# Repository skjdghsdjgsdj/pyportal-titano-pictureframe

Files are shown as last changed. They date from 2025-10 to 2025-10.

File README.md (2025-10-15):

# PyPortal Titano Picture Frame

Use a [PyPortal Titano](https://www.adafruit.com/product/4444) as a little picture frame with images pulled from your favorites in [Immich](https://immich.app/).

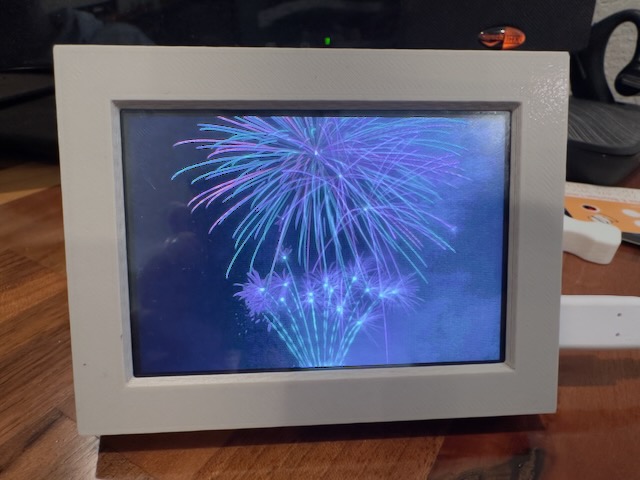
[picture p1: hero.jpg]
The PyPortal Titano picture frame in action


The project is structured into three main parts:

* `client`: the CircuitPython code that runs on the PyPortal Titano
* `server`: A Python Flask HTTP server that connects to your Immich instance and does image conversions and other middleware between Immich and the picture frame
* `hardware`: The OpenSCAD files for the 3D printed parts

## Setup

### Things you'll need

For hardware, you'll need this stuff. Yay, no soldering or wiring at all!

* An [Adafruit PyPortal Titano](https://www.adafruit.com/product/4444)
* A microSD card
* A 3D printer
* A USB C-to-C cable
* A USB C power supply
* 8× M3x4 screws
* A computer with a USB C port and a microSD card reader, or an SD card reader with a microSD-to-SD adapter (many cards come with this)

You might want a USB C cable with a right angle connector, but it's not necessary.

You also need:

* [Immich](https://immich.app/) up and running somewhere
* A computer that runs 24/7 to run a Python server
* A very basic understanding of how to run Python scripts and install packages

Each picture takes up about 500 KB of space on the card. A 1 GB card therefore can hold about 2000 pictures, and a 16 GB card holds around 30,000. microSD cards are pretty cheap so I'd suggest getting a reasonably big one, or a good sized one you already have laying around. The card isn't written to very often, so I wouldn't bother with "endurance" cards or other expensive ones. Besides, if the SD card dies, just put in a new one and the picture frame will sync everything automatically again.

### Building everything

First, set up the software environment for your server. The server acts as a bridge between the picture frame and Immich to download images and convert them to a format compatible with the PyPortal Titano. The PyPortal Titano doesn't talk directly to Immich.

1. Clone this Git repository, or download a `.zip` of it and extract it.
2. `cd` to the `server` directory. All the subsequent commands you'll run should be within the `server` directory.
3. Copy `.env.example` to `.env`, then modify `.env` as documented within that file.
4. Create a virtual environment: `cd` to the `server` directory, create an environment with `python3 -m venv ./.venv`, and activate it with `source .venv/bin/activate`.
5. Install the necessary Python libraries with `pip3 install -r requirements.txt`
6. Launch the server with `python3 server.py`. Note the IP address and port number of your server; you'll need that next.

Before moving on, open your Immich instance and favorite some pictures (not videos). The server will pick from your favorites when listing the available pictures for the picture frame.

With the server done, you can move into the rest of the assembly.

1. [Install CircuitPython 10 on the board](https://learn.adafruit.com/adafruit-pyportal-titano/circuitpython#set-up-circuitpython-quick-start-3050161).
2. Print the enclosure:
    * Use 0.2mm layer height.
    * Use any filament you want. PLA is easiest.
    * Do not use supports.
    * Orient the parts such that the case is upside down, the backplate prints with the flat part facing down, and the stand as-is.
3. Format the microSD card in your computer as FAT32 for cards up to and including 32 GB, or exFAT for cards larger than 32 GB (instructions for [macOS](https://support-en.sandisk.com/app/answers/detailweb/a_id/35101/~/steps-to-format-a-memory-card-on-macos), [Windows](https://support-en.sandisk.com/app/answers/detailweb/a_id/9063/~/instructions-to-format-a-memory-card-on-windows)). This will delete all the data on the card!
3. Assemble the enclosure:
    1. If installed, peel off the protective plastic cover on the PyPortal Titano's screen.
    2. Insert the microSD card into the board until it clicks into place.
    3. Place the board into the enclosure with the screen facing the opening and the USB C port and microSD card slot facing their respective locations.
    4. Use 4× screws to secure the board into the enclosure's standoffs. Do not tighten the screws any further than necessary to keep the board in place.
    5. Screw the backplate into place with the other 4× screws. Orient the backplate so the hole labeled "reset" aligns with the reset button on the board. Again, only tighten the screws as much as necessary.
    6. Install the stand by pressing one side of it into the mounting point on the backplate, then gently squeezing the stand into place and pressing the other side into its mounting point.
    7. If you want to use the ambient light sensor, shove a little piece of 1.75mm transparent filament (any material) into the hole near the microSD card until it's flush with the outside of the case. If you don't care about having the screen adjust its brightness automatically, or you odn't have any transparent filament, you can skip this.
4. Install the software for the picture frame:
    1. Clone this Git repository, or download it as a `.zip` and extract it.
    2. Copy `client/settings.toml.example` to `client/settings.toml` and open it in a text editor.
    3. At a minimum, look at the section "Settings you'll have to change" and change those values. There are more settings you can change if you want, but it's not necessary.
    4. Copy everything in the `client` directory, but not the `client` directory itself, to the `CIRCUITPY` drive. It might take a while. Eventually the board should reboot, connect to Wi-Fi, and start showing your pictures!

## Usage

It's very easy: favorite a picture in your Immich instance, and eventually it'll appear in the rotation of pictures on the picture frame. Unfavorite a picture to remove it from the rotation. If you replace an image with another upload, the replacement will be detected too.

The picture frame syncs itself every hour by default. Only static images will show up, so favorited videos, motion pictures, and other types of assets will be ignored.

The picture frame can work offline, but it's not really meant to. If there's a Wi-Fi connection error, either at startup or when syncing, an icon appears on the screen and the sync is skipped. The next one will attempt to reconnect and the process repeats. In the meantime, assets directly on the SD card are shown in the slideshow.

When powering up the picture frame with assets already on the SD card, the slide show starts immediately and then the sync runs, so you can start the picture frame with at least some picture showing up. If there are no assets on the SD card, like when you first power on the picture frame, a sync is forced and if it fails, a message stating that there are no pictures is shown until the next sync attempt.

## Background info

The overall workflow of the picture frame is:

1. PyPortal starts up, mounts its SD card to `/sd`, initializes its external ESP32 for Wi-Fi, and connects.
2. At startup, and then every hour by default, it:
    1. Connects to the Flask server and does a `GET` for `/assets`. This endpoint returns a JSON map of favorited applicable asset UUIDs in Immich to MD5 hashes of their checksums. In Immich, this is the `/api/search/metadata` endpoint, which also supports pagination.
    2. A list of all assets on the SD card are indexed. If a UUID is found on the SD card that isn't in the JSON map from the server, or if the UUID does exist but the hash differs, that asset on the SD card is deleted.
    3. A list of assets to download is assembled: this is every UUID in the JSON map that's not on the SD card or ones with differing MD5 hashes.
    4. Each asset (if any) is downloaded as a `.bmp` from the `/asset/<uuid>` endpoint in the Flask server. Before each individual download, disk space is freed if necessary. More specifically, the asset is downloaded by the Flask server's `/asset/<uuid>` endpoint which in turn gets it from Immich's `/api/assets/<uuid>/thumbnail` endpoint, resized to 480x320 with letterboxing/pillarboxing added as necessary to ensure the image is exactly that size, then streamed back as an uncompressed paletted `image/bmp`.

Assets are stored in `/sd/assets/<uuid>/<md5>.bmp`. Bitmaps are used instead of JPEGs because `displayio.OnDiskBitmap` is needed to directly stream the bitmap data from the SD card to the screen. The JPEGs are too big to decode and buffer into the tiny amount of memory available. This is also one of the key reasons the Flask server exists: the images in Immich are way, way too big to manipulate directly on the board, but trivial for Python's Pillow library to do so on a real server.

There is no persistent index of images on the card. Instead, the filesystem is iterated to find candidate files and a random one picked. This, presumably, will be slow if there are a lot of images. The code won't randomly show the same image twice in a row unless there's only one image available.

The MD5 hash is used to detect checksum changes. This happens if a user replaces an image in-place in Immich and therefore the one stored on the SD card should be updated too.

So why not a Raspberry Pi? Yes, there are other options out there, and more powerful ones. Why did I make this instead?

* For better or worse, I don't need to expose my Immich instance.
* The PyPortal Titano is overall a great board for this application: it's little, it's got a built-in screen, and (mostly) easy to work with.
* I don't need to run and maintain a full-blown Linux computer like a Raspberry Pi.
* I can just unplug it and not worry about corrupting a filesystem. Even if the SD card gets corrupted, no code is stored there so it doesn't matter.
* If I want to change from Immich to something else, the client code isn't really tied to Immich and just the server needs updates. The client doesn't actually know it's talking to Immich.
* I just wanted to make it.

If you want a much more capable and productive option, I believe there are other projects out there that let you do slideshows of your Immich library on a Raspberry Pi or other spare computer.

If you want to monitor the health of the Flask server, make `GET` requests to `/health-check`. It will respond with an empty body and HTTP 204.

## Troubleshooting

Before doing anything, [connect to the board's serial console](https://learn.adafruit.com/welcome-to-circuitpython/the-repl) and watch the output. Errors are likely to show up here and be more informative than what the board shows on its screen.

* **It's super slow to download my pictures.** If you have a bunch of favorited pictures in Immich it might take a _long_ time to download everything the first time. Each favorited picture gets downloaded as an uncompressed bitmap because that's all that's supported by the board and its limited memory, and the board's Wi-Fi is already pretty slow. Subsequent syncs should be much faster as the board will only download new or updated files and delete old ones instead of downloading everything each time.
* **No pictures are available.** Make sure you favorited at least one picture. The server will only consider assets in Immich that:
  * Are favorited
  * Are _not_ motion pictures
  * Are _not_ offline
  * Have a type of "image", so not videos or other types
* **I favorited some pictures but they aren't showing up in the slideshow.** The picture frame checks for favorited pictures at startup, and then periodically by default every hour. You can adjust this timing by changing `SYNC_INTERVAL_SECONDS` in `settings.toml`.
* **The picture frame is working, but it takes a few seconds for a picture to _slowly_ draw itself into the screen.** Such are the limitations of the board. It's by design a very slow CPU and, more importantly, has very little memory. This means it has to read a bitmap image, which is relatively large, directly off the SD card instead of first buffering it into memory. You can try to use a faster SD card, but the board is only so fast itself.
* **I'm using Cloudflare and having problems.** You may need to disable bot protections for Immich and/or your Flask server, depending on which is exposed to the internet and how things are connected together. Cloudflare may be thinking, and correctly so, that bots are attempting to access your Immich instance or the Flask server because the code sends a default user-agent for CircuitPython. Note that for the picture frame to work, the Flask server has to be directly accessible from the picture frame, but the picture frame doesn't access Immich directly so that can be more protected.
* **The picture frame keeps randomly rebooting itself.** If plugged into your computer, the board might think it's being written to, and CircuitPython automatically reboots when that happens to load code changes. When using the picture frame as just...a picture frame, plug it into a USB C power supply instead of a computer.
* **The stand is flimsy and it keeps falling over.** The tolerances for the stand are pretty tight, and fiddling with the stand a bunch will eventually loosen it too. Print another stand, and that's not an improvement, a new backplate. If that doesn't help, tweak the tolerances in the OpenSCAD file to suit your needs. The default values work well me for me with PLA printed on a Prusa MK3s+ with the 0.20mm quality profile.

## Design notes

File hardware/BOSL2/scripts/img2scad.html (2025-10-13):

# Convert image to OpenSCAD array

This utility accepts an image that can be displayed in your browser, and converts it to grayscale expanded to use the maximum possible luminance range. The file types supported depend on your browser. Alpha channel is ignored. After processing the image as desired, you may save it as an OpenSCAD array.

Keep the output image width small! A large size results in a huge output file when converting an image to text data.

Select an image

You can also paste an image (Ctrl+V) into this section from your clipboard.

Transformations Rescale original width (px):
⟲ Rotate left ⟳ Rotate right
⇋ Flip horizontal ⇵ Flip vertical

Top

Left

Crop

Right

Bottom

Appearance

See:
Luma (https://en.wikipedia.org/wiki/Luma_(video))

NTSC grayscale formula NTSC Y′ = 0.299R + 0.587G + 0.114B
Rec. 601: Average human perception of color luminance
sRGB linear luminance sRGB Y′ = 0.2126R + 0.7152G + 0.0722B
Rec. 709: Digital HD, used by OpenSCAD surface()

Invert brightness

Filter Gaussian blur radius (pixels):
Sharpen radius (pixels):
Edge detect radius (pixels):

Contrast Compress brightness above and below threshold
to maximum and minimum brightness.

0

Threshold Level between black (-128) and white (127)
around which to adjust contrast.

0

Output Normalize range to [0,1] — uses [0,255] if unset

Name of array:

Save as OpenSCAD array ≈ 0 bytes

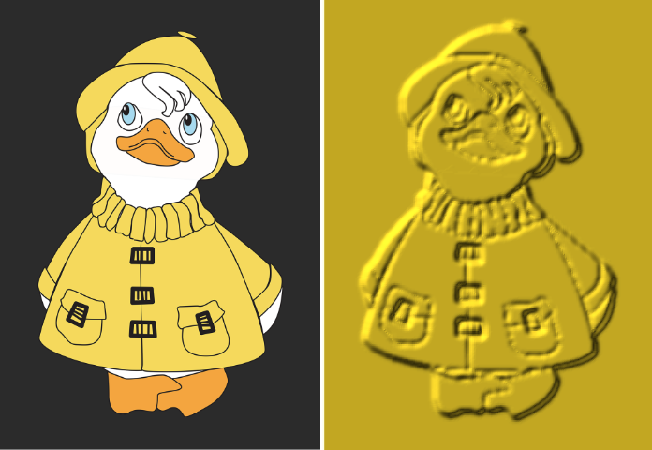
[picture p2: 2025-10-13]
hardware/BOSL2/images/WilburTex01.png

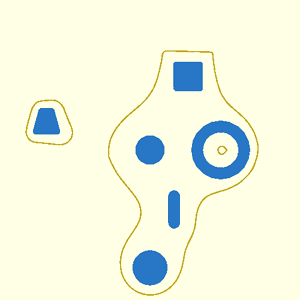
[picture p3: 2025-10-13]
hardware/BOSL2/images/metaball_demo2d.gif

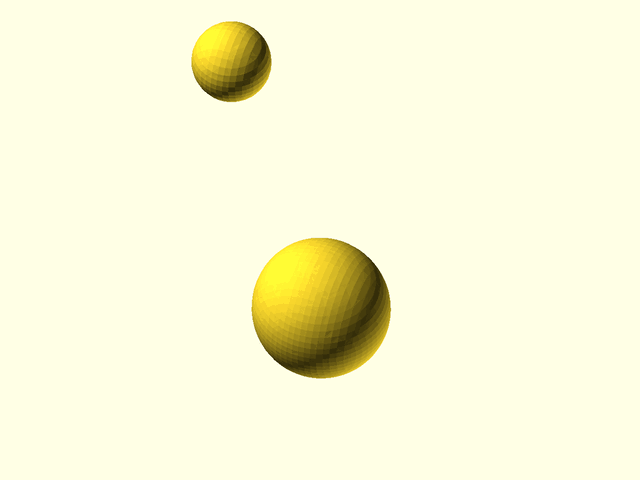
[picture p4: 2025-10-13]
hardware/BOSL2/images/metaball_demo.gif

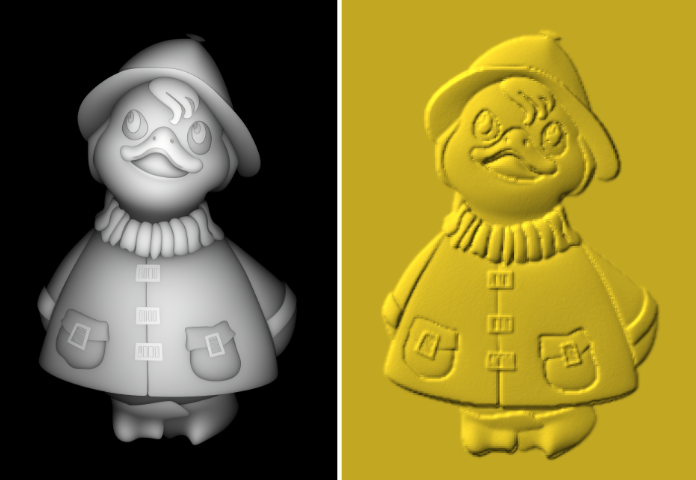
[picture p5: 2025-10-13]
hardware/BOSL2/images/WilburTex02.png

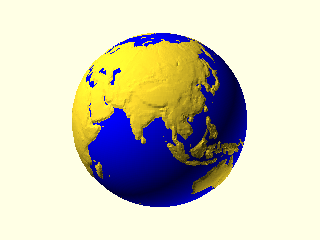
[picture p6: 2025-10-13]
hardware/BOSL2/images/globe_animation.png

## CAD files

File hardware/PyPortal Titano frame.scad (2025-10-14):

include <BOSL2/std.scad>
include <BOSL2/shapes3d.scad>

Viewable_width = 75;
Viewable_depth = 50.4;
Surface_height = 1.5;
Bezel = 9.3;
PyPortal_total_height = 11;
Light_pipe = true;
MicroSD_cutout = true;
Standoff_height = 4;

$fn = ($preview ? 36 : 72);

if (false && $preview) {
	color("#339933")
	translate([0.8, -27.7, -4.5])
	rotate([-90, 0, 0])
	import("4444 PyPortal Titano.stl");
}

function total_width() = Viewable_width + Bezel * 2 + Surface_height * 2;
function total_depth() = Viewable_depth + Bezel * 2 + Surface_height * 2;

module usb_c_hole(depth) {
	hole_width = 10.5;
	hole_radius = 2;

	for (y = [-hole_width / 2 + hole_radius, hole_width / 2 - hole_radius]) {
		translate([0, y, 0])
		rotate([90, 0, 90])
		cylinder(r = hole_radius, h = Surface_height);
	}
	
	translate([Surface_height / 2, 0, 0])
	cube([Surface_height, hole_width - hole_radius * 2, hole_radius * 2], center = true);
}

module case() {
	render()
	difference() {
		translate([0, 0, Surface_height / 2])
		cube([
			total_width(),
			total_depth(),
			Surface_height
		], center = true);

		prismoid(
			size1 = [Viewable_width, Viewable_depth],
			size2 = [Viewable_width + Surface_height * 2, Viewable_depth + Surface_height * 2],
			h = Surface_height
		);
	}

	for (x = [-total_width() / 2 + 12, total_width() / 2 - 12]) {
		for (y = [
			-5 / 2 + total_depth() / 2 - Surface_height,
			5 / 2 - total_depth() / 2 + Surface_height
			]
		) {
			translate([x, y, -PyPortal_total_height])
			render()
			difference() {
				union() {
					translate([0, 0, 2])
					prismoid(
						size2 = [6, 0],
						size1 = [6, 6],
						h = 5,
						shift = [0, y > 0 ? 5 / 2 : -5 / 2]
					);
					
					translate([0, 0, 2 / 2])
					cube([6, 6, 2], center = true);
				}
				
				cylinder(d = 2.85, h = 3);
			}
		}
	}

	render()
	difference() {
		translate([0, 0, -PyPortal_total_height / 2])
		cube([
			Viewable_width + Bezel * 2 + Surface_height * 2,
			Viewable_depth + Bezel * 2 + Surface_height * 2,
			PyPortal_total_height
		], center = true);
		
		translate([0, 0, -PyPortal_total_height / 2])
		cube([
			Viewable_width + Bezel * 2,
			Viewable_depth + Bezel * 2,
			PyPortal_total_height
		], center = true);
		
		translate([total_width() / 2 - Surface_height, -18.2, -7.2])
		usb_c_hole();
		
		if (MicroSD_cutout) {
			translate([total_width() / 2 - Surface_height, -3.4, -6.5])
			rotate([90, 0, 90])
			prismoid(
				size1 = [11.5, 1.5],
				size2 = [11.5 + Surface_height * 2, 1.5 + Surface_height * 2],
				h = Surface_height
			);
		}

		if (Light_pipe) {
			translate([total_width() / 2 - Surface_height, 4.4, -2.5])
			rotate([90, 0, 90])
			cylinder(d = 1.8, h = Surface_height);
		}
	}

	for (x = [43.975, -42.375]) {
		for (y = [30.075, -30.25]) {
			translate([x, y, 0])
			render()
			translate([0, 0, -Standoff_height])
			difference() {
				cylinder(d = 4, h = Standoff_height);
				cylinder(d = 2.85, h = Standoff_height);
			}
		}
	}
}

module backplate() {
	reset_hole_x = 2.6;
	reset_hole_y = 23;

	render()
	difference() {
		translate([-total_width() / 2, -total_depth() / 2, -PyPortal_total_height - Surface_height])
		cube([total_width(), total_depth(), Surface_height]);
		
		for (x = [-total_width() / 2 + 12, total_width() / 2 - 12]) {
			for (y = [
				-5 / 2 + total_depth() / 2 - Surface_height,
				5 / 2 - total_depth() / 2 + Surface_height
				]
			) {
				translate([x, y, -PyPortal_total_height - Surface_height])
				cylinder(d = 3.3, h = Surface_height);
			}
		}
		
		translate([reset_hole_x, reset_hole_y, -PyPortal_total_height - Surface_height])
		cylinder(d = 1.6, h = Surface_height);
	
		translate([reset_hole_x - 2.8, reset_hole_y + 3, -PyPortal_total_height - Surface_height])
		mirror([1, 0, 0])
		linear_extrude(0.4)
		text("RESET ↓", font = "SF Compact Display:style=Bold", halign = "right", valign = "bottom", size = 5);
	}
	
	for (x = [-10 - 5 / 2, 10 + 5 / 2]) {
		translate([x, total_depth() / 4, -PyPortal_total_height - Surface_height - 5 / 2])
		render()
		difference() {
			union() {
			rotate([90, 0, 90])
				cylinder(d = 7, h = 5, center = true);
		
				translate([0, 0, 5 / 4])
				cube([5, 7, 7 / 2], center = true);
			}
			
			rotate([90, 0, 90])
			cylinder(d = 3.2, h = 5, center = true);
		}
	}
}

module stand() {
	size = 3.1;
	inset = 5;

	stand_depth = total_depth() - total_depth() / 4;
	y = -total_depth() / 2 + stand_depth / 2;
	z = -PyPortal_total_height - Surface_height - inset / 2;

	translate([0, y, z])
	render()
	difference() {
		union() {
			cube([20, stand_depth, size], center = true);
			
			translate([0, stand_depth / 2, 0])
			rotate([90, 0, 90])
			cylinder(d = size, h = 20 + inset * 2, center = true);
		}
		
		translate([0, size * 2, 0])
		cube([20 - size * 2 - 5, stand_depth, size * 2], center = true);
	}
}

//color("#ffffee") case();
//color("#eeeeff") backplate();
color("#ffeeff") stand();

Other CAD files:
hardware/BOSL2/constants.scad
hardware/BOSL2/nema_steppers.scad
hardware/BOSL2/screw_drive.scad
hardware/BOSL2/affine.scad
hardware/BOSL2/attachments.scad
hardware/BOSL2/ball_bearings.scad
hardware/BOSL2/beziers.scad
hardware/BOSL2/bosl1compat.scad
hardware/BOSL2/bottlecaps.scad
hardware/BOSL2/builtins.scad
hardware/BOSL2/color.scad
hardware/BOSL2/comparisons.scad
hardware/BOSL2/coords.scad
hardware/BOSL2/cubetruss.scad
hardware/BOSL2/distributors.scad
hardware/BOSL2/drawing.scad
hardware/BOSL2/examples/BOSL2logo.scad
hardware/BOSL2/examples/attachments.scad
hardware/BOSL2/examples/boolean_geometry.scad
hardware/BOSL2/examples/fractal_tree.scad
hardware/BOSL2/examples/lsystems.scad
hardware/BOSL2/examples/orientations.scad
hardware/BOSL2/examples/spherical_patch.scad
hardware/BOSL2/examples/spring_handle.scad
hardware/BOSL2/examples/worldmap_360x180.scad
hardware/BOSL2/fnliterals.scad
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

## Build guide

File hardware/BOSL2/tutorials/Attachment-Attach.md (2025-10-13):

[Prev: Using align()](Tutorial-Attachment-Align)

# Attachment using attach()

The `attach()` module can stick the child object to the parent object
by matching a designated face on the child to a specified face on the
parent.  Unlike `position()` and `align()`, the `attach()` module may
change the orientation and spin of the child.

## The Parent Coordinate System

When you attach a child object, it appears on the parent relative to
the local coordinate system of the parent at the anchor. 
To understand what this means, imagine the perspective of an ant walking on a
sphere.  The meaning of UP varies depending on where on the sphere the
ant is standing.  If you **attach** a cylinder to the sphere then the cylinder will
be "up" from the ant's perspective.   The first example shows a
cylinder placed with `position()` so it points up in the global parent
coordinate system.  The second example shows how `attach()` points the
cylinder UP from the perspective of an ant standing at the anchor
point on the sphere.  

```openscad-3D
include<BOSL2/std.scad>
sphere(40)
    position(RIGHT+TOP) cylinder(r=8,h=20);
```

```openscad-3D
include<BOSL2/std.scad>
sphere(40)
    attach(RIGHT+TOP) cylinder(r=8,h=20);
```

In the example above, the cylinder's center point is attached to the
sphere, pointing "up" from the perspective of the sphere's surface.
For a sphere, a surface normal is defined everywhere that specifies
what "up" means.  But for other objects, it may not be so obvious.
Usually at edges and corners the direction is the average of the
direction of the faces that meet there.

It's obvious to the ant which direction is UP, and hence corresponds
to the Z axis, on the surface of the sphere she inhabits.  But in
order to define the ant's local coordinate system we also need to
decide where the X and Y directions are.  This is obvious an arbitrary
choice.  In BOSL2 this is called the "spin" direction for the anchor.  

When you specify an anchor for use with attachment you are actually
specifying both an anchor position but also an anchor direction (the Z
axis) and the anchor's spin so that you fully define the parent
coordinate systemer and a spin.  If you want to visualize this
direction you can use anchor arrows.

## Anchor Directions and Anchor Arrows

For the ant on the sphere it is obvious which direction is UP; that
direction corresponds to the Z+ axis.  The location of the X and Y
axes is less clear and in fact it may be arbitrary.  One way that is
useful to show the position and orientation of an anchor point is by
attaching an anchor arrow to that anchor.  As noted before, the small
red flag points in the direction of the anchor's Y+ axis when the spin
is zero.

```openscad-3D
include <BOSL2/std.scad>
cube(18, center=true)
    attach(LEFT+TOP)
        anchor_arrow();
```

For large objects, you can change the size of the arrow with the `s=` argument.

```openscad-3D
include <BOSL2/std.scad>
sphere(d=100)
    attach(LEFT+TOP)
        anchor_arrow(s=50);
```

To show all the standard cardinal anchor points, you can use the [show_anchors()](https://github.com/BelfrySCAD/BOSL2/wiki/attachments.scad#module-show_anchors) module.

```openscad-3D;Big
include <BOSL2/std.scad>
cube(20, center=true)
    show_anchors();
```

```openscad-3D;Big
include <BOSL2/std.scad>
cylinder(h=25, d=25, center=true)
    show_anchors();
```

```openscad-3D;Big
include <BOSL2/std.scad>
sphere(d=40)
    show_anchors();
```

For large objects, you can again change the size of the arrows with the `s=` argument.

```openscad-3D;Big
include <BOSL2/std.scad>
prismoid(150,60,100)
    show_anchors(s=45);
```

## Parent-Child Anchor Attachment (Double Argument Attachment)

The `attach()` module has two different modes of operation,
parent-child anchor attachment and parent anchor attachment.  These
are also called double argument attachment and single argument
attachment.  The parent-child anchor attachment, with two arguments,
is usually easier to use and is more powerful because it supports
alignment.  When just starting out with attachment, we recommend that
you focus on this form of attachment.  

When you use parent-child anchor attachment you give a
parent anchor and a child anchor.  Imagine pointing the anchor arrows
on the two objects directly at each other and pushing them together in
the direction of the arrows until they touch.  In many of the examples
below we show first the two objects with their anchor arrows and then
the result of the attach operation using those anchors.

```openscad-3D
include <BOSL2/std.scad>
cube(50,anchor=BOT) attach(TOP,BOT) anchor_arrow(30);
right(60)cylinder(d1=30,d2=15,h=25) attach(BOT,BOT) anchor_arrow(30);
```

```openscad-3D
include <BOSL2/std.scad>
cube(50,anchor=BOT)
  attach(TOP,BOT) cylinder(d1=30,d2=15,h=25);
```

This example produces the same result as using `align()`, but if the
parent anchor is not horizontal, then the child is reoriented:

```openscad-3D
include <BOSL2/std.scad>
prismoid([50,50],[35,35],h=50,anchor=BOT) attach(RIGHT,BOT) anchor_arrow(30);
right(60)cylinder(d1=30,d2=15,h=25) attach(BOT,BOT) anchor_arrow(30);
```

```openscad-3D
include <BOSL2/std.scad>
prismoid([50,50],[35,35],h=50,anchor=BOT)
  attach(RIGHT,BOT) cylinder(d1=30,d2=15,h=25);
```

In this case we attach the curved side of the cone to a cube by lining
up the anchor arrows:

```openscad-3D
include <BOSL2/std.scad>
cube(50,center=true) attach(RIGHT,BOT) anchor_arrow(30);
right(80)cylinder(d1=30,d2=15,h=25) attach(LEFT,BOT) anchor_arrow(30);
```

```openscad-3D
include <BOSL2/std.scad>
cube(50,center=true)
  attach(RIGHT,LEFT) cylinder(d1=30,d2=15,h=25);
```

Note that this form of attachent overrides any anchor or orientation
specified in the child: **with parent-child anchor attachment the
`anchor=` and `orient=` parameters to the child are ignored.**

When you specify attachment using a pair of anchors, the attached
child can spin around the parent anchor while still being attached at
the designated anchors: specifying the anchors leaves one unspecified
degree of freedom.  As noted earlier, this ambiguity is resolved by anchors having a
defined spin which specifies where the Y+ axis is located.
The way that BOSL2 positions objects can be understood by viewing the
anchor arrows as shown above, or you can remember these rules:
1. When attaching to the TOP or BOTTOM: the FRONT of the child points to the front if possible;  otherwise the TOP of the child points BACK.
2. When attaching to other faces, if possible the child's UP anchor will point UP; otherwise, the BACK of the child points up (so the FRONT is pointed down).  

To show how this works we use this prismoid where the blue arrow is
pointing to the front and the green arrow points up.  Also note that
the front left edge is the only right angle.  

```openscad-3D
include <BOSL2/std.scad>
color_this("orange")
prismoid([8,8],[6,6],shift=-[1,1],h=8) {
     attach(TOP,BOT) anchor_arrow(color=[0,1,0],s=12);
     attach(FWD,BOT) anchor_arrow(s=12);     
}
```

If we attach this to the TOP by the LEFT side then we get the result
below.  Notice how the green UP arrow is pointing back.

```openscad-3D
include <BOSL2/std.scad>
cube(30) attach(TOP,LEFT)
color_this("orange")
  prismoid([8,8],[6,6],shift=-[1,1],h=8) {
    attach(TOP,BOT) anchor_arrow(color=[0,1,0],s=12);
    attach(FWD,BOT) anchor_arrow(s=12);     
  }
```

If we attach to the RIGHT using the same LEFT side anchor on the
prismoid then we get the result below.  Note that the green UP anchor
is pointing UP, in accordance with rule 2 from above.  

```openscad-3D
include <BOSL2/std.scad>
cube(30) attach(RIGHT,LEFT)
color_this("orange")
  prismoid([8,8],[6,6],shift=-[1,1],h=8) {
    attach(TOP,BOT) anchor_arrow(color=[0,1,0],s=12);
    attach(FWD,BOT) anchor_arrow(s=12);     
  }
```

The green UP arrow can always be arranged to point up unless we attach
either the top or bottom to one of the cube's vertical faces.  Here we
attach the bottom so you can still see both arrows.  The blue FRONT
arrow on the object is pointing down, as expected based on rule 2.  

```openscad-3D
include <BOSL2/std.scad>
cube(30) attach(RIGHT,BOT)
color_this("orange")
  prismoid([8,8],[6,6],shift=-[1,1],h=8) {
    attach(TOP,BOT) anchor_arrow(color=[0,1,0],s=12);
    attach(FWD,BOT) anchor_arrow(s=12);     
  }
```

What do you do if the direction the child appears is not the direction
you need?  To address this issue `attach()` provides a `spin=`
parameter which spins the attached child around the axis defined by
the joined anchor vectors.  Here is the last example with a rotation
applied to bring the front anchor back to the front:

```openscad-3D
include <BOSL2/std.scad>
cube(30) attach(RIGHT,BOT,spin=-90)
color_this("orange")
  prismoid([8,8],[6,6],shift=-[1,1],h=8) {
    attach(TOP,BOT) anchor_arrow(color=[0,1,0],s=12);
    attach(FWD,BOT) anchor_arrow(s=12);     
  }
```

Be aware that specifying `spin=` to `attach()` is not equivalent to
using the `spin=` argument to the child.  Unlike `orient=` and
`anchor=`, which are ignored, the child `spin=` argument is still
respected, but it may be difficult to figure out which axis it will
rotate on.  It is more intuitive to ignore the child spin parameter
and only use the spin parameter to `attach()`.  The spin must be
scalar but need not be a multiple of 90 degrees.

```openscad-3D
include <BOSL2/std.scad>
cube(30) attach(RIGHT,BOT,spin=-37)
color_this("orange")
  prismoid([8,8],[6,6],shift=-[1,1],h=8) {
    attach(TOP,BOT) anchor_arrow(color=[0,1,0],s=12);
    attach(FWD,BOT) anchor_arrow(s=12);     
  }
```

By default, `attach()` places the child exactly flush with the surface
of the parent.  Sometimes it's useful to have the child overlap the
parent by translating it into the parent.  You can do this with the
`overlap=` argument to `attach()`.  A positive value will cause the
child to overlap the parent, and a negative value will move the child
away from the parent, leaving a small gap.  In the first example we use a very large value of
overlap so the cube is sunk deeply into the parent.  In the second
example a large negative overlap value raises the child high above the
parent.  

```openscad-3D
include <BOSL2/std.scad>
cuboid(50)
    attach(TOP,BOT,overlap=15)
        color("green")cuboid(20);
```

```openscad-3D
include <BOSL2/std.scad>
cube(50,center=true)
    attach(TOP,BOT,overlap=-20)
        cyl(d=20,h=20);
```

Another feature provided by the double argument form of `attach()` is
alignment, which works in a similar way to `align()`.  You can specify
`align=` to align the attached child to an edge or corner.  The
example below shows five different alignments.  

```openscad-3D;Big
include <BOSL2/std.scad>
module thing(){
  color_this("orange")
    prismoid([8,8],[6,6],shift=-[1,1],h=8) {
      attach(TOP,BOT) anchor_arrow(color=[0,1,0],s=12);
      attach(FWD,BOT) anchor_arrow(s=12);     
    }
}
prismoid([50,50],[35,35],h=25,anchor=BOT){
  attach(TOP,BOT,align=FRONT) thing();
  attach(RIGHT,BOT,align=BOT) thing();    
  attach(RIGHT,BACK,align=FRONT) thing();
  attach(FRONT,BACK,align=BOT,spin=45) thing();
  attach(TOP,RIGHT,align=RIGHT,spin=90) thing();
}
```

As with `align()` if you turn an object 90 degrees it can match up
with parallel edges, but if you turn it an arbitrary angle, a corner
of the child will contact the edge of the parent.  Also like align()
the anchor points of the parent and child are aligned but this does
not necessarily mean that edges line up neatly when the shapes have
varying angles.  This misalignment is visible in the object attached
at the RIGHT and aligned to the FRONT.

You may be wondering why all this fuss with align is necessary.
Couldn't you just attach an object at an anchor on an edge?  When you
do this, the object will be attached using the edge anchor, which is
not perpendicular to the faces of the object.  The example below shows
attachment to an edge anchor and also a corner anchor.  

```openscad-3D
include <BOSL2/std.scad>
cube(30)
   color("orange"){
     attach(RIGHT+FRONT,BOT) 
        prismoid([8,8],[6,6],shift=-[1,1],h=8);
     attach(TOP+LEFT+FWD,BOT)
        prismoid([8,8],[6,6],shift=-[1,1],h=8);
   }
```

When using the `align` option to `attach()` you can also set `inset`,
which works the same way as the `inset` parameter to `align()`.  It
shifts the child away from the edge or edges where it is aligned by
the specified amount.  

```openscad-3D
include <BOSL2/std.scad>
prismoid([50,50],[50,25],25){
  attach(FWD,BOT,align=TOP,inset=3) color("lavender")cuboid(5);
  attach(FWD,BOT,align=BOT+RIGHT,inset=3) color("purple")cuboid(5);
}
```

The last capability provided by `attach()` is to attach the child
**inside** the parent object.  This is useful if you want to subtract
the child from the parent.  Doing this requires using tagged
operations with `diff()` which is explained in more detail below. 
For the examples here, note that the `diff()` and `tag()` operations
that appear cause the child to be subtracted.  We return to the
example that started this section, with anchor arrows shown on the two
objects.  

```openscad-3D
include <BOSL2/std.scad>
cube(50,anchor=BOT) attach(TOP) anchor_arrow(30);
right(60)cylinder(d1=30,d2=15,h=25) attach(TOP) anchor_arrow(30);
```

Inside attachment is activated using `inside=true` and it lines up the
anchor arrows so they point together the **same** direction instead of
opposite directions like regular outside attachment.  The result in
this case is appears below, where we have cut away the front half to
show the interior: 

```openscad-3D
include <BOSL2/std.scad>
back_half(s=200)
diff()
cube(50,anchor=BOT)
  attach(TOP,TOP,inside=true)
    cylinder(d1=30,d2=15,h=25);
```

The top of the cavity has a thin layer on it, which occurs because the
two objects share a face in the difference.  To fix this you can use
the `shiftout` parameter to `attach()`.  In this case you could also
use a negative `overlay` value, but the `shiftout` parameter shifts
out in every direction that is needed, which may be three directions
if you align the child at a corner.  The above example looks like this
with with the shift added:

```openscad-3D
include <BOSL2/std.scad>
back_half(s=200)
diff()
cube(50,anchor=BOT)
  attach(TOP,TOP,inside=true,shiftout=0.01)
    cylinder(d1=30,d2=15,h=25);
```

Here is an example of connecting the same object on the right, but
this time with the BOTTOM anchor.  Note how the BOTTOM anchor is
aligned to the RIGHT so it is parallel and pointing in the same
direction as the RIGHT anchor.  

```openscad-3D
include <BOSL2/std.scad>
back_half(s=200)
diff()
cuboid(50)
  attach(RIGHT,BOT,inside=true,shiftout=0.01)
    cylinder(d1=30,d2=15,h=25);
```

Here is an example where alignment moves the object into the corner,
and we benefit from shiftout providing 3 dimensions of adjustment:

```openscad-3D
include <BOSL2/std.scad>
diff()
cuboid(10)
  attach(TOP,TOP,align=RIGHT+FWD,inside=true,shiftout=.01)
    cuboid([2,5,9]);
```

As with `position()`, with any use of `attach()` you can still apply your own translations and
other transformations even after attaching an object.  However, the
order of operations now matters.  If you apply a translation outside
of the anchor then it acts in the parent's global coordinate system, so the
child moves up in this example, where the light gray shows the
untranslated object.  

```openscad-3D
include <BOSL2/std.scad>
cuboid(50){
  %attach(RIGHT,BOT)
    cyl(d1=30,d2=15,h=25);
  up(13)
    color("green") attach(RIGHT,BOT)
      cyl(d1=30,d2=15,h=25);
}
```

On the other hand, if you put the translation between the attach and
the object in your code, then it will act in the local coordinate system of
the parent at the parent's anchor, so in the example below it moves to the right.  

```openscad-3D
include <BOSL2/std.scad>
cuboid(50){
  %attach(RIGHT,BOT)
    cyl(d1=30,d2=15,h=25);
  color("green") attach(RIGHT,BOT)
    up(13)
      cyl(d1=30,d2=15,h=25);
}
```

Parent-child Anchor attachment with CENTER anchors can be surprising because the anchors
both point upwards, so in the example below, the child's CENTER anchor
points up, so it is inverted when it is attached to the parent cone.
Note that the anchors are CENTER anchors, so the bases of the anchors are
hidden in the middle of the objects.  

```openscad-3D
include <BOSL2/std.scad>
cylinder(d1=30,d2=15,h=25) attach(CENTER) anchor_arrow(40);
right(40)cylinder(d1=30,d2=15,h=25) attach(CENTER) anchor_arrow(40);
```

```openscad-3D
include <BOSL2/std.scad>
cylinder(d1=30,d2=15,h=25)
    attach(CENTER,CENTER)
        cylinder(d1=30,d2=15,h=25);
```

Is is also possible to attach to edges and corners of the parent
object.  The anchors for edges spin the child so its BACK direction is
aligned with the edge.  If the edge belongs to a top or bottom
horizontal face, then the BACK directions will point clockwise around
the face, as seen from outside the shape.  (This is the same direction
required for construction of valid faces in OpenSCAD.)  Otherwise, the
BACK direction will point upwards.

Examine the red flags below, where only edge anchors appear on a
prismoid.  The top face shows the red flags pointing clockwise.
The sloped side edges point along the edges, generally upward, and
the bottom ones appear to point counter-clockwise, but if we viewed
the shape from the bottom they would also appear clockwise.  

```openscad-3D;Big
include <BOSL2/std.scad>
prismoid([100,175],[55,88], h=55)
  for(i=[-1:1], j=[-1:1], k=[-1:1])
    let(anchor=[i,j,k])
       if (sum(v_abs(anchor))==2)
         attach(anchor,BOT)anchor_arrow(40);
```

In this example cylinders sink half-way into the top edges of the
prismoid:

```openscad-3D;Big
include <BOSL2/std.scad>
$fn=16;
r=6;
prismoid([100,175],[55,88], h=55){
   attach([TOP+RIGHT,TOP+LEFT],LEFT,overlap=r/2) cyl(r=r,l=88+2*r,rounding=r);
   attach([TOP+FWD,TOP+BACK],LEFT,overlap=r/2) cyl(r=r,l=55+2*r, rounding=r);   
}
```

This type of edge attachment is useful for attaching 3d edge masks to
edges:

```openscad-3D;Big
include <BOSL2/std.scad>
$fn=32;
diff()
cuboid(75)
   attach([FRONT+LEFT, FRONT+RIGHT, BACK+LEFT, BACK+RIGHT],
          FWD+LEFT,inside=true)
     rounding_edge_mask(l=76, r1=8,r2=28);
```

## Parent Anchor Attachment (Single Argument Attachment)

The second form of attachment is parent anchor attachment, which just
uses a single argument.  This form of attachment is less useful in
general and does not provide alignment.  When you give `attach()` a parent anchor but no child anchor it
orients the child according to the parent anchor direction but then
simply places the child based on its internally defined anchor at the
parent anchor position.  For most objects the default anchor is the
CENTER anchor, so objects will appear sunk half-way into the parent.

```openscad-3D
include <BOSL2/std.scad>
cuboid(30)
    attach(TOP)
        color("green")cuboid(10);
```

Some objects such as `cylinder()`, `prismoid()`, and `anchor_arrow()` have default anchors on the bottom, so they will appear
on the surface.  For objects like this you can save a little bit of
typing by using parent anchor attachment.  But in the case of `cube()`
the anchor is not centered, so the result is:

```openscad-3D
include <BOSL2/std.scad>
cube(30)
    attach(TOP)
        color("green")cube(10);
```

In order to make single argument attachment produce the results you
need you will probably need to change the child anchor.  Note that unlike
parent-child anchor attachment, **with parent anchor attachment the `anchor=` and `orient=` arguments
are respected.**  We could therefore place a cuboid like this:

```openscad-3D
include <BOSL2/std.scad>
cuboid(30)
  attach(RIGHT)
      color("green")cuboid(10,anchor=BOT);
```

If you need to place a cuboid at the anchor point but need it anchored
relative to one of the bottom edge or corner anchors then you can do
that with parent anchor attachment:

```openscad-3D
include <BOSL2/std.scad>
cuboid(30)
  attach(RIGHT)
      color("green")cuboid(10,anchor=BOT+FWD);
```

Another case where single argument attachment is useful is when the
child doesn't have proper attachment support.
If you use double argument attachment in such cases the results will
be incorrect because the child doesn't properly respond to the
internally propagated anchor directives.  With single argument
attachment, this is not a problem: the origin
of the child will be placed at the parent anchor point.  One module
without attachment support is `linear_extrude()`.  

```openscad-3D
include <BOSL2/std.scad>
cuboid(20)
  attach(RIGHT)
     color("red")linear_extrude(height=2) star(n=7,ir=3,or=7);
```

As noted earlier, you can set `orient=` for children with parent
anchor attachment, though the behavior may not be intuitive because
the attachment process transforms the coordinate system and the
orientation is done in the attached coordinate system.  It may be
helpful to start with the object attached to TOP and recall the rules
from the previous section about how orientation works.  The same rules
apply here.  Note that the forward arrow is pointing down after
attaching the object on the RIGHT face.

```openscad-3D
include <BOSL2/std.scad>
cuboid(20){
  attach(RIGHT)
     color_this("red")cuboid([2,4,8],orient=RIGHT,anchor=RIGHT)
        attach(FWD) anchor_arrow();
  attach(TOP)
     color_this("red")cuboid([2,4,8],orient=RIGHT,anchor=RIGHT)
            attach(FWD) anchor_arrow();
}
```

## Positioning and Attaching Multiple Children

You can attach or position more than one child at a time by enclosing them all in braces:

```openscad-3D
include <BOSL2/std.scad>
cube(50, center=true) {
    attach(TOP) cylinder(d1=50,d2=20,h=20);
    position(RIGHT) cylinder(d1=50,d2=20,h=20);
}
```

If you want to attach the same shape to multiple places on the same parent, you can pass the
desired anchors as a list to the `attach()` or `position()` modules:

```openscad-3D
include <BOSL2/std.scad>
cube(50, center=true)
    attach([RIGHT,FRONT],TOP) cylinder(d1=35,d2=20,h=25);
```

```openscad-3D
include <BOSL2/std.scad>
cube(50, center=true)
    position([TOP,RIGHT,FRONT]) cylinder(d1=35,d2=20,h=25);
```

## Attaching 2D Children

You can use attachments in 2D as well.  As usual for the 2D case you
can use TOP and BOTTOM as alternative to BACK and FORWARD.  With
parent-child anchor attachment you cannot use the spin parameter to
`attach()` nor can you specify spin to the child.  Spinning the child
on the Z axis would rotate the anchor arrows out of alignment.  

```openscad-2D
include <BOSL2/std.scad>
rect(50){
    attach(RIGHT,FRONT)
        color("red")trapezoid(w1=30,w2=0,h=30);
    attach(LEFT,FRONT,align=[FRONT,BACK],inset=3)
        color("green") trapezoid(w1=25, w2=0,h=30);
}
```

```openscad-2D
include <BOSL2/std.scad>
diff()
circle(d=50){
    attach(TOP,BOT,overlap=5)
        trapezoid(w1=30,w2=0,h=30);
    attach(BOT,BOT,inside=true)
        tag("remove")
        trapezoid(w1=30,w2=0,h=30);
}        
```

[Next: Attachable Parts](Tutorial-Attachment-Parts)

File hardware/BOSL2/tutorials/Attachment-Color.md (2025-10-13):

[Prev: Attachable Parts](Tutorial-Attachment-Parts)

## Coloring Attachables
Usually, when coloring a shape with the `color()` module, the parent color overrides the colors of
all children.  This is often not what you want:

```openscad-3D
include <BOSL2/std.scad>
$fn = 24;
color("red") spheroid(d=3) {
    attach(CENTER,BOT) color("white") cyl(h=10, d=1) {
        attach(TOP,BOT) color("green") cyl(h=5, d1=3, d2=0);
    }
}
```

If you use the `recolor()` module, however, the child's color
overrides the color of the parent.  This is probably easier to understand by example:

```openscad-3D
include <BOSL2/std.scad>
$fn = 24;
recolor("red") spheroid(d=3) {
    attach(CENTER,BOT) recolor("white") cyl(h=10, d=1) {
        attach(TOP,BOT) recolor("green") cyl(h=5, d1=3, d2=0);
    }
}
```

Be aware that `recolor()` will only work if you avoid using the native
`color()` module.  Also note that `recolor()` still affects all its
children.  If you want to color an object without affecting the
children you can use `color_this()`.  See the difference below:

```openscad-3D
include <BOSL2/std.scad>
$fn = 24;
recolor("red") spheroid(d=3) {
    attach(CENTER,BOT) recolor("white") cyl(h=10, d=1) {
        attach(TOP,BOT)  cyl(h=5, d1=3, d2=0);
    }
}
right(5)
recolor("red") spheroid(d=3) {
    attach(CENTER,BOT) color_this("white") cyl(h=10, d=1) {
        attach(TOP,BOT)  cyl(h=5, d1=3, d2=0);
    }
}
```

Similar modules exist to provide access to the highlight and
background modifiers.   You can specify `highlight()` and then later
`highlight(false)` to control the use of the `#` modifier.  Similarly
you can use `ghost()` and `ghost(false)` to provide more control of
the `%` modifier.  And as with color, you can also use
`highlight_this()` and `ghost_this()` to affect just one child without
affecting its descendents.  

As with all of the attachable features, these color, highlight and ghost modules only work
on attachable objects, so they will have no effect on objects you
create using `linear_extrude()` or `rotate_extrude()`.  

[Next: Tagged Operations with Attachments](Tutorial-Attachment-Tags)

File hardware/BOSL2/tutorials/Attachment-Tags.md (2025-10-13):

[Prev: Using Color with Attachments](Tutorial-Attachment-Color)

# Tagged Operations

BOSL2 introduces the concept of tags.  Tags are names that can be given to attachables, so that
you can refer to them when performing `diff()`, `intersect()`, and `conv_hull()` operations.
Each object can have no more than one tag at a time.  The reason that
tagged operations are important is that they allow you to perform
operations on objects that are at different levels in the parent-child
hierarchy.  The most common example is to use `attach()` to create a
child but subtract it from the parent.

To tag an object preceed the object with the `tag()` module and give
it a name: `tag("my_cube") cube(10)`.  The tag will apply to the
object and all of its children until another tag module.  If you need
to remove a tag you can use `tag("")`.  If you need to tag just one
object and do not want to tag any of its descendents you can do this
using `tag_this(name) object();`

### `diff([remove], [keep])`
The `diff()` operator is used to difference away all shapes marked with the tag(s) given to
`remove`, from the other shapes.  

For example, to difference away a child cylinder from the middle of a parent cube, you can
do this:

```openscad-3D
include <BOSL2/std.scad>
diff("hole")
cube(100, center=true)
    tag("hole")cylinder(h=101, d=50, center=true);
```

The `keep=` argument takes tags for shapes that you want to keep in the output.

```openscad-3D
include <BOSL2/std.scad>
diff("dish", keep="antenna")
cube(100, center=true)
    attach([FRONT,TOP], overlap=33) {
        tag("dish") cylinder(h=33.1, d1=0, d2=95);
        tag("antenna") cylinder(h=33.1, d=10);
    }
```

Remember that tags applied with `tag()` are inherited by children.  In this case, we need to explicitly
untag the first cylinder (or change its tag to something else), or it
will inherit the "keep" tag and get kept.  

```openscad-3D
include <BOSL2/std.scad>
diff("hole", "keep")
tag("keep")cube(100, center=true)
    attach([RIGHT,TOP]) {
        tag("") cylinder(d=95, h=5);
        tag("hole") cylinder(d=50, h=11, anchor=CTR);
    }
```

You can apply a tag that is not propagated to the children using
`tag_this()`.  The above example could then be redone:

```openscad-3D
diff("hole", "keep")
tag_this("keep")cube(100, center=true)
    attach([RIGHT,TOP]) {
        cylinder(d=95, h=5);
        tag("hole") cylinder(d=50, h=11, anchor=CTR);
    }
```    

You can of course apply `tag()` to several children.

```openscad-3D
include <BOSL2/std.scad>
diff("hole")
cube(100, center=true)
    attach([FRONT,TOP], overlap=20)
        tag("hole") {
            cylinder(h=20.1, d1=0, d2=95);
            down(10) cylinder(h=30, d=30);
        }
```

Many of the modules that use tags have default values for their tags.  For diff the default
remove tag is "remove" and the default keep tag is "keep".  In this example we rely on the
default values:

```openscad-3D
include <BOSL2/std.scad>
diff()
sphere(d=100) {
    tag("keep")xcyl(d=40, l=120);
    tag("remove")cuboid([40,120,100]);
}
```

The parent object can be differenced away from other shapes.  Tags are inherited by children,
though, so you will need to set the tags of the children as well as the parent.

```openscad-3D
include <BOSL2/std.scad>
diff("hole")
tag("hole")cube([20,11,45], center=true)
    tag("body")cube([40,10,90], center=true);
```

Tags (and therefore tag-based operations like `diff()`) only work correctly with attachable
children.  However, a number of built-in modules for making shapes are *not* attachable.
Some notable non-attachable modules are `text()`, `linear_extrude()`, `rotate_extrude()`,
`polygon()`, `polyhedron()`, `import()`, `surface()`, `union()`, `difference()`,
`intersection()`, `offset()`, `hull()`, and `minkowski()`.

To allow you to use tags-based operations with non-attachable shapes, you can wrap them with the
`force_tag()` module to specify their tags.  For example:

```openscad-3D
include <BOSL2/std.scad>
diff("hole")
cuboid(50)
  attach(TOP)
    force_tag("hole")
      rotate_extrude()
        right(15)
          square(10,center=true);
```

### `intersect([intersect], [keep])`

To perform an intersection of attachables, you can use the `intersect()` module.  This is
specifically intended to address the situation where you want intersections involving a parent
and a child, something that is impossible with the native `intersection()` module.  This module
treats the children in three groups: objects matching the `intersect` tags, objects matching
the tags listed in `keep` and the remaining objects that don't match any listed tags.  The
intersection is computed between the union of the `intersect` tagged objects and the union of
the objects that don't match any listed tags.  Finally the objects listed in `keep` are union
ed with the result.  

In this example the parent (untagged) is intersected with a conical
bounding shape, which is tagged with the intersect tag.

```openscad-3D
include <BOSL2/std.scad>
intersect("bounds")
cube(100, center=true)
    tag("bounds") cylinder(h=100, d1=120, d2=95, center=true, $fn=72);
```

In this example the child objects are intersected with the bounding box parent.  

```openscad-3D
include <BOSL2/std.scad>
intersect("pole cap")
cube(100, center=true)
    attach([TOP,RIGHT]) {
        tag("pole")cube([40,40,80],center=true);
        tag("cap")sphere(d=40*sqrt(2));
    }
```

The default `intersect` tag is "intersect" and the default `keep` tag is "keep".  Here is an
example where "keep" is used to keep the pole from being removed by the intersection. 

```openscad-3D
include <BOSL2/std.scad>
intersect()
cube(100, center=true) {
    tag("intersect")cylinder(h=100, d1=120, d2=95, center=true, $fn=72);
    tag("keep")zrot(45) xcyl(h=140, d=20, $fn=36);
}
```

### `conv_hull([keep])`
You can use the `conv_hull()` module to hull shapes together.  Objects
marked with the keep tags are excluded from the hull and unioned into the final result.
The default keep tag is "keep".  

```openscad-3D
include <BOSL2/std.scad>
conv_hull()
cube(50, center=true) {
    cyl(h=100, d=20);
    tag("keep")xcyl(h=100, d=20);
}
```

[Next: Edge Profiling with Attachment](Tutorial-Attachment-Edge-Profiling)

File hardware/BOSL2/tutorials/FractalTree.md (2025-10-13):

# Fractal Tree Tutorial

<!-- TOC -->

### Start with a Tree Trunk

Firstoff, include the BOSL2 library, then make a starting module that just has a tapered cylinder for the tree trunk.

```openscad-3D
include <BOSL2/std.scad>
module tree(l=1500, sc=0.7)
    cylinder(h=l, d1=l/5, d2=l/5*sc);
tree();
```

### Attaching a Branch

You can attach a branch to the top of the trunk by using `attach()` as a child of the trunk cylinder.

```openscad-3D
include <BOSL2/std.scad>
module tree(l=1500, sc=0.7)
    cylinder(h=l, d1=l/5, d2=l/5*sc)
        attach(TOP)
            yrot(30) cylinder(h=l*sc, d1=l/5*sc, d2=l/5*sc*sc);
tree();
```

### Replicating the Branch

Instead of attaching each branch individually, you can make multiple copies of one branch, that are rotated relative to each other.

```openscad-3D
include <BOSL2/std.scad>
module tree(l=1500, sc=0.7)
    cylinder(h=l, d1=l/5, d2=l/5*sc)
        attach(TOP)
            zrot_copies(n=2)  // Replicate that branch
                yrot(30) cylinder(h=l*sc, d1=l/5*sc, d2=l/5*sc*sc);
tree();
```

### Use Recursion

Since branches look much like the main trunk, we can make the tree recursive. Don't forget the termination clause, or else it'll try to recurse forever!

```openscad-Med
include <BOSL2/std.scad>
module tree(l=1500, sc=0.7, depth=10)
    cylinder(h=l, d1=l/5, d2=l/5*sc)
        attach(TOP)
            if (depth>0)  { // Important!
                zrot_copies(n=2)
                yrot(30) tree(depth=depth-1, l=l*sc, sc=sc);
            }
tree();
```

### Make it Not Flat

A flat planar tree isn't what we want, so lets bush it out a bit by rotating each level 90 degrees.

```openscad-Med
include <BOSL2/std.scad>
module tree(l=1500, sc=0.7, depth=10)
    cylinder(h=l, d1=l/5, d2=l/5*sc)
        attach(TOP)
            if (depth>0) {
                zrot(90)  // Bush it out
                zrot_copies(n=2)
                yrot(30) tree(depth=depth-1, l=l*sc, sc=sc);
            }
tree();
```

### Adding Leaves

Let's add leaves. They look much like squashed versions of the standard teardrop() module, so lets use that.

```openscad-Big
include <BOSL2/std.scad>
module tree(l=1500, sc=0.7, depth=10)
    cylinder(h=l, d1=l/5, d2=l/5*sc)
        attach(TOP)
            if (depth>0) {
                zrot(90)
                zrot_copies(n=2)
                yrot(30) tree(depth=depth-1, l=l*sc, sc=sc);
            } else {
                yscale(0.67)
                teardrop(d=l*3, l=1, anchor=BOT, spin=90);
            }
tree();
```

### Adding Color

We can finish this off with some color. The `color()` module will force all it's children and
their descendants to the new color, even if they were colored before. The `recolor()` module,
however, will only color children and decendants that don't already have a color set by a more
nested `recolor()`.

```openscad-Big
include <BOSL2/std.scad>
module tree(l=1500, sc=0.7, depth=10)
    recolor("lightgray")
    cylinder(h=l, d1=l/5, d2=l/5*sc)
        attach(TOP)
            if (depth>0) {
                zrot(90)
                zrot_copies(n=2)
                yrot(30) tree(depth=depth-1, l=l*sc, sc=sc);
            } else {
                recolor("springgreen")
                yscale(0.67)
                teardrop(d=l*3, l=1, anchor=BOT, spin=90);
            }
tree();
```

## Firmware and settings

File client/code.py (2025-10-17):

import os
import random
import re
import time

# CircuitPython doesn't have the typing library, so this is for the IDE's sake and gets ignored on the board
try:
	# noinspection PyUnusedImports
	from typing import Iterable, Any, List, Final
except ImportError:
	pass

import adafruit_connection_manager
import adafruit_requests
import board
import digitalio
import displayio
import storage
from adafruit_bitmap_font import bitmap_font
from adafruit_display_text.bitmap_label import Label
from adafruit_esp32spi import adafruit_esp32spi
from adafruit_esp32spi.adafruit_esp32spi import ESP_SPIcontrol
from digitalio import DigitalInOut
import adafruit_sdcard

# no REPL on the built-in screen
board.DISPLAY.root_group = None

# reset the display rotation in case it was messed with
board.DISPLAY.rotation = 0

# turn off the speaker to save a token amount of power
speaker = digitalio.DigitalInOut(board.SPEAKER_ENABLE)
speaker.switch_to_output(True)
speaker.value = False

class UI:
	"""
	The UI.
	"""

	def __init__(self, display):
		"""
		Sets up the UI.

		:param display: Board's display, which is probably board.DISPLAY
		"""

		self.display = display
		self.display.auto_refresh = False

		self.image: displayio.TileGrid | None = None

		self._init_components()

		display.root_group = self.root_group

	def _init_components(self) -> None:
		"""
		Sets up all the UI components in their default states.
		"""

		self.root_group = displayio.Group()
		self.font = bitmap_font.load_font("/bdf/sf-compact-display.bdf")

		offline_bitmap = displayio.OnDiskBitmap("/img/offline.bmp")
		self.offline_icon = displayio.TileGrid(
			offline_bitmap,
			pixel_shader = offline_bitmap.pixel_shader,
			x = self.display.width - 35,
			y = self.display.height - 35
		)
		self.offline_icon.hidden = True # just so the UI is less cluttered at first
		self.root_group.append(self.offline_icon)

		self.status_label = Label(
			font = self.font,
			text = "",
			anchor_point = (0.0, 1.0),
			anchored_position = (10, self.display.height - 20),
			color = (255, 255, 255),
		)

		self.status_label_shadow = Label(
			font = self.font,
			text = "",
			anchor_point = (0.0, 1.0),
			anchored_position = (10 + 1, self.display.height - 20 + 1),
			color = (0, 0, 0)
		)

		self.root_group.append(self.status_label_shadow)
		self.root_group.append(self.status_label)

	def show_image(self, path: str | None, buffer_first: bool = False):
		"""
		Shows a slideshow image or placeholder text if one isn't provided. When showing an existing image, it is
		buffered to internal storage first if buffer_first is True and rendered from there; otherwise the exact storage
		path is used.

		:param path: Path to the image to show, or None to show placeholder text
		:param buffer_first: If true, buffer the image to internal storage first. Note that some boards, the PyPortal
		Titano included, this is hideously slow and much WORSE than reading directly from the SD card.
		:return: self
		"""

		if self.image is not None:
			self.root_group.remove(self.image)

		if path is not None:
			print(f"Showing image: {path}")

			if buffer_first:
				print(f"Buffering image...")
				bytes_read = 0
				with open(path, "rb") as input_file:
					with open("/tmp.bmp", "wb") as output_file:
						buffer = input_file.read(10240)
						while buffer:
							bytes_read += len(buffer)
							print(f"Copied {bytes_read} bytes")
							output_file.write(buffer)
							buffer = input_file.read(10240)
				print("Done buffering")
				path = "/tmp.bmp"

			bitmap = displayio.OnDiskBitmap(open(path, "rb"))
			self.image = displayio.TileGrid(bitmap, pixel_shader = bitmap.pixel_shader)

			self.root_group.insert(0, self.image)
		else:
			print("Showing empty image")

		return self

	def set_status(self, status: str | None):
		"""
		Sets the text of the status label at the bottom-left of the screen or hides it if None.

		:param status: Status text to show or hides label if None
		:return: self
		"""

		if status is None:
			self.status_label.hidden = True
			self.status_label_shadow.hidden = True
		else:
			self.status_label.hidden = False
			self.status_label_shadow.hidden = False

			self.status_label.text = status
			self.status_label_shadow.text = status

		return self

	def render(self) -> None:
		self.display.refresh()

class App:
	"""
	The main app flow.
	"""

	def __init__(self, asset_path: str = "/sd/assets"):
		"""
		Sets up the main app.

		:param asset_path: Path to where assets are stored on the SD card
		"""

		self.ui = UI(board.DISPLAY)
		self.asset_path: Final[str] = asset_path

		# the underlying ESP32 hardware; should only get initialized once at startup
		self.esp = None

		# is not None once there's a successful Wi-Fi connection
		self.requests: adafruit_requests.Session | None = None

	def start(self) -> None:
		"""
		Entry point for the app; loops forever.
		"""

		self._mount_sd()

		has_assets = False
		if not any(self._walk_fs_assets()): # if the SD card is empty, then download assets first
			print("SD card has no assets; attempting to download them before starting slideshow")
			if self._auto_connect(): # only attempt a sync if online
				self._sync()
		else:
			has_assets = True
			print("SD card has at least one asset; starting slideshow first")

		self._loop(sync_immediately = has_assets)

	def _loop(self, sync_immediately: bool = False) -> None:
		"""
		Main loop that runs once all the hardware is setup and initial sync completed. Loops forever.

		:param: sync_immediately: If True, run a sync immediately after rendering the first image. If false, wait until
		the usual timeout before running a sync. Only affects the first image render.
		"""

		last_image_path = None
		last_sync = None if sync_immediately else time.monotonic()
		while True:
			# pick a random asset and show it
			path = self._get_random_sd_asset_path(avoid = last_image_path)
			if path is None: # nothing on the SD card
				self.ui.show_image(None)
				self.ui.set_status("No images available").render()
			elif last_image_path != path: # show a new image
				last_image_path = path
				self.ui.set_status(None).render()
				self.ui.show_image(path).render() # a separate render to get rid of the first before slowly drawing image

			# see if a sync is needed or was forced
			now = time.monotonic()
			if last_sync is None or now - last_sync > os.getenv("SYNC_INTERVAL_SECONDS", 3600):
				last_sync = now
				print("Sync timeout reached or sync forced")
				if self._auto_connect():
					print("Starting sync")
					self._sync()
				else:
					print("Skipping sync, offline")

			time.sleep(os.getenv("REFRESH_INTERVAL_SECONDS", 300))

	@staticmethod
	def _is_uuid(string: str) -> bool:
		"""
		Validates that the given string is a valid lowercase UUID.
		:param string: Candidate string to validate
		:return: True if the string is a valid UUID, False otherwise
		"""
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

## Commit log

2025-10-15 Settings docs and more control; avoid showing the same image when randomly picking the next one
    [code.py]
2025-10-15 Fixed a bit of syncing UI jankiness
    [code.py]
2025-10-15 Fixed SSID not showing up if <= 20 chars
    [code.py]
2025-10-15 Set the board to a good known state at startup
2025-10-15 Retry ESP32 init if it fails
    [code.py]
2025-10-15 Retry SD card init if it fails
    [code.py]
2025-10-17 Attempt to increase SPI clock speed for faster SD card access
